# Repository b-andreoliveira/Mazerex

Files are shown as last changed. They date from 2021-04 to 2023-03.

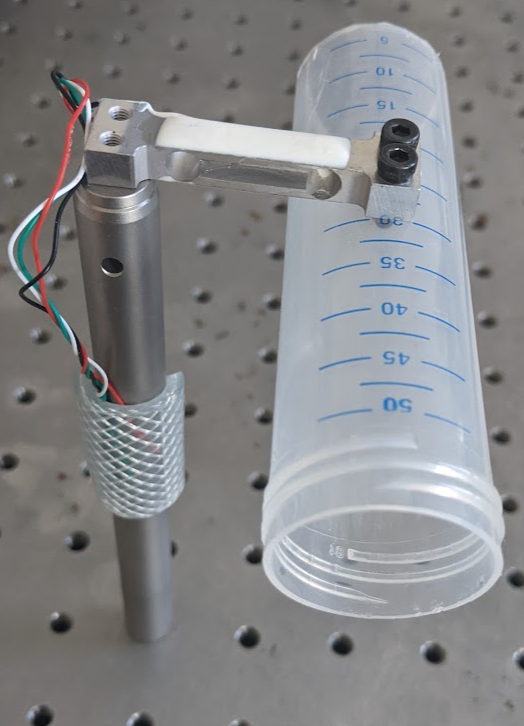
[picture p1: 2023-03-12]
final/weighing_tunnel.png

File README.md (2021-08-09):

# Mazerex

This GitHub page is dedicated to documenting the deleoping process of Mazerex.

For the Internship II report of the MSc Neuroscinces, please go to the 'final' folder, as it contains the final version of the codes and the 3D-printable files.

The python script running in both RaspberryPi I and RaspberryPi II is the same.

 - André Oliveira Borba

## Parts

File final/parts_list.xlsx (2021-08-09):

Item | Quantity | Product no. | Brand/Company | Price per unit (in US$) | Price (in US$) | Link
RaspberryPi 4B | 2 |  | Raspberry foundation | 51.03 | 102.06 | https://www.raspberrystore.nl/PrestaShop/raspberry-pi-v4/227-raspberry-pi-4b2gb-765756931175.html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
Arduino-nano | 1 | #A000005 | Arduino | 23.76 | 23.76 | https://store.arduino.cc/arduino-nano
FED3 | 4 | N/A | Kravitz lab | 178.51 | 714.04 | https://github.com/KravitzLabDevices/FED3
RFID reader ID-20LA (125 kHz) | 4 | #SEN-11828 | Sparkfun | 34.95 | 139.8 | https://www.sparkfun.com/products/11828
RFID breakout board with USB reader | 4 | #SEN-09963 | Sparkfun | 27.95 | 111.8 | https://www.sparkfun.com/products/9963
RFID-tag glass capsule (125 kHz) | 6 | #SEN-09416 | Sparkfun | 4.95 | 29.7 | https://www.sparkfun.com/products/9416
100g load cell | 4 | #SEN-14727 | Sparkfun | 8.95 | 35.8 | https://www.sparkfun.com/products/14727
OpenScale | 4 | #SEN-13261 | Sparkfun | 31.95 | 127.8 | https://www.sparkfun.com/products/13261
green LEDs | 4 | #COM-09592 | Sparkfun | 0.35 | 1.4 | https://www.sparkfun.com/products/9592
red LEDs | 4 | #COM-09590 | Sparkfun | 0.35 | 1.4 | https://www.sparkfun.com/products/9590
piezo transducer (passive buzzer) | 4 | #PS1240P02CT3 | TKD | 0.44 | 1.76 | https://www.kingstate.com.tw/index.php?do=product&id=14
flying-fish infra-red proximity receptor | 4 | #100314 | Yanmis | 9.59 | 38.36 | https://www.amazon.co.uk/dp/B07MJF9Z4K?uh_it=406ac83ca40dd442a51c544e3dd4ecd5_CT
flying saucer running wheel | 4 |  | Ware pet products | 6.29 | 25.16 | https://www.warepet.com/product/03281/flying-saucer-sm.html
generic servomotor | 4 | #ROB-09065 | Sparkfun | 8.95 | 35.8 | https://www.sparkfun.com/products/9065
rotary encoder | 4 | #REC16B50-201 | Copal Electronics | 15.34 | 61.36 | https://nl.rs-online.com/web/p/optical-rotary-encoders/1825634/
relay PCB suitable for Arduino | 1 | #TC-9072496 | Conrad | 9.39 | 9.39 | https://www.amazon.co.uk/dp/B073W6QD9P
stainless steel optical posts 150mm | 4 | #TR150/M | Thor labs | 7.9 | 31.6 | https://www.thorlabs.com/newgrouppage9.cfm?objectgroup_id=1266
stainless steel optical posts 300mm | 4 | #TR300/M | Thor labs | 12.26 | 49.04 | https://www.thorlabs.com/newgrouppage9.cfm?objectgroup_id=1266
25mm optical construction rails 1200mm long | 4 | #XE25L1200/M | Thor labs | 63.37 | 253.48
optical post holders Ø12.7mm, 20mm long | 8 | #PH20/M | Thor labs | 7.74 | 61.92
drop-in T-nuts | 10 | #XE252T2 | Thor labs | 33.28 | 33.28
90º angle post clamps | 8 | #RA90/M | Thor labs | 10.75 | 86
3D-printed doors | 4 | N/A | N/A | N/A | N/A | N/A
3D-printed RFID-antenna supports | 4 | N/A | N/A | N/A | N/A | N/A
3D-printed ladder/slit juncture | 4 | N/A | N/A | N/A | N/A | N/A
TOTAL ESTIMATED PRICE |  |  |  |  | 1974.71
FED3 |  |  |  | Price item | for 1 fed | for 4 feds
Adafruit M0 Adalogger | 4 | #2796 | Adafruit Industries | 20.84 | 20.84
8GB SD card | 4 | #TS8GSDHC10 | Transcend | 13.22 | 13.22
3.6V Lithium-ion rechargeable battery | 4 | #2447-3005 | Ansmann | 39.85 | 39.85
Interrupt button | 4 | #JST PH2 | Adafruit Industries | 2.96 | 2.96
RTC module | 4 | #PCF8523 | Adafruit Industries | 4.97 | 4.97
NeoPixel Stick RGB LED 8 | 4 | #WS2812 | Adafruit Industries | 5.98 | 5.98
Stepper motor PM geared | 4 | #MIKROE-1530 | MikroEletronika | 8 | 8
Sharp memory display breakout | 4 | #3502 | Adafruit Industries | 24.95 | 24.95
1K resistors | 12 | #CFR-25JB-52-1K | Yaego | 0.0258 | 0.0774
Motor shield breakout TB6612 | 4 | #2448 | Adafruit Industries | 4.95 | 4.95
Photointerruptor | 12 | #GP1A57HRJ00F | SHARP/Socle Technology | 3.455 | 10.365
Custom PCB | 4 | N/A | OSHPARK | 42.35 | 42.35
 |  |  |  |  | 0
 |  |  |  |  | 0
 |  |  |  |  | 178.5124

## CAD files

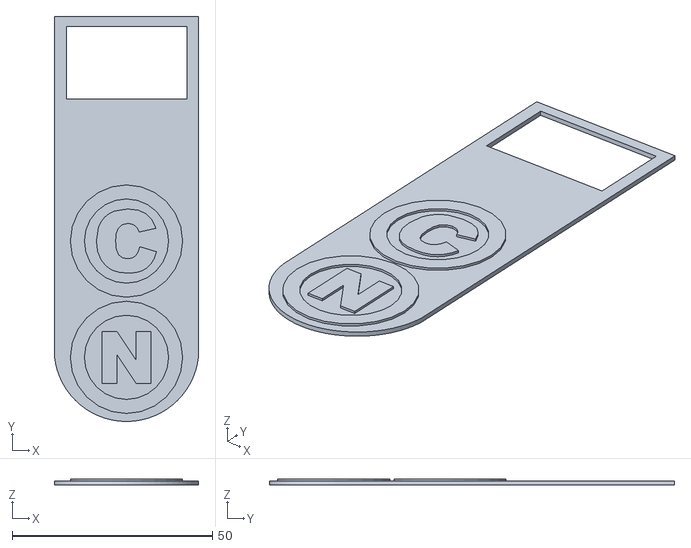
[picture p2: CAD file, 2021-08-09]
final/3D files/mazerex_door.stl
36.0 x 101.0 x 1.50

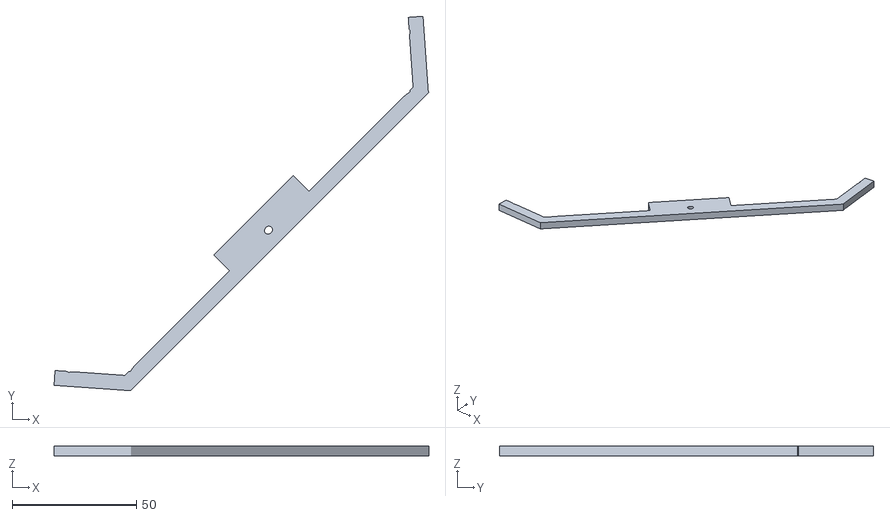
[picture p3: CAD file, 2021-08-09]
final/3D files/servo_arm_new.stl
151.2 x 150.9 x 4.00

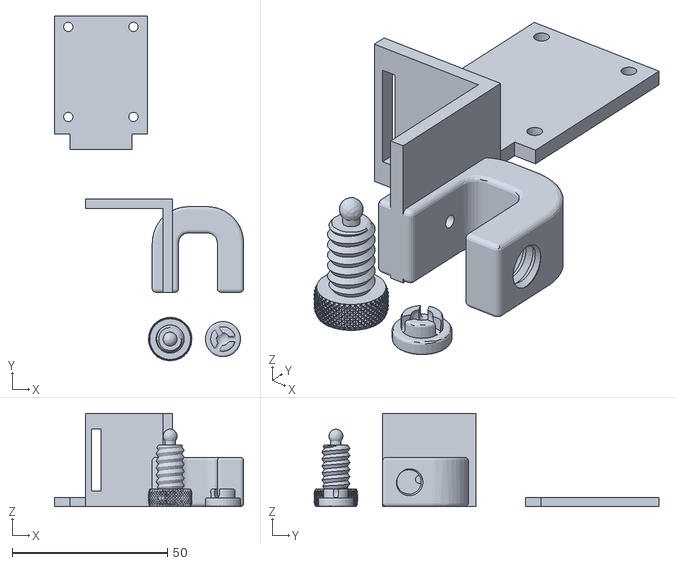
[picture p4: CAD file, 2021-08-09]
final/3D files/RFID_antenna_adaptor.stl
61.0 x 111.1 x 30.0

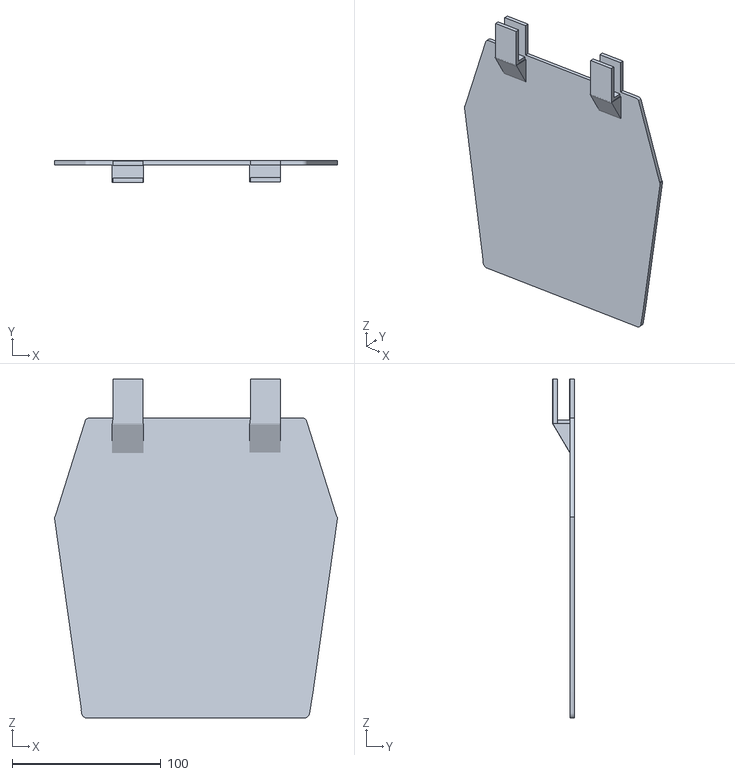
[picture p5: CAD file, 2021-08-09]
final/3D files/mazerex_divisor.stl
190.4 x 14.7 x 227.7

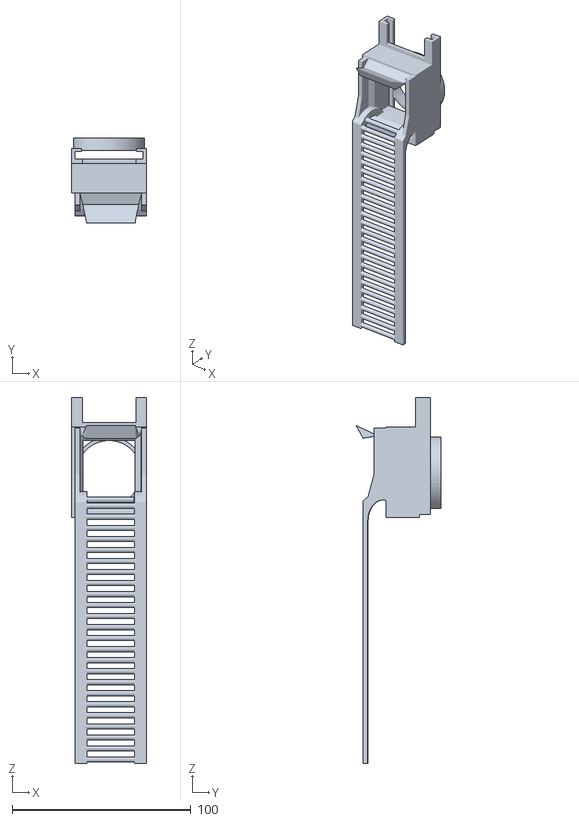
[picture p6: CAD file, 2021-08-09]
final/3D files/ladder-slit_mazerex.stl
42.0 x 47.6 x 204.9

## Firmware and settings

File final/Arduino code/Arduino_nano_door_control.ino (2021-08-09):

#include<Servo.h>
Servo servo1;     // Servo 1
#include<Servo.h>
Servo servo2;     
#include<Servo.h>
Servo servo3;     
#include<Servo.h>
Servo servo4;     

const int servoPin1 = 5;  // output to servos 1-4
const int servoPin2 = 6;
const int servoPin3 = 3;
const int servoPin4 = 9;

const int slowness = 8;   //slowness factor, ms wait between 1deg movements, change to set speed
                           
//SERVO 1
const int d1_food = 75;   //servo positions; calibrate manually//servo positions; calibrate manually
const int d1_social = 125;  
const int d1_close = 100;

//SERVO 2 
const int d2_food = 120;   
const int d2_social = 75;  
const int d2_close = 100; 

//SERVO 3
const int d3_food = 100;   
const int d3_social = 60;  
const int d3_close = 80; 

//SERVO 4
const int d4_food = 45;   
const int d4_social = 95;  
const int d4_close = 70; 

// input commands from Pi 
const int Pd1_food = 2;  
const int Pd1_social = 4;

const int Pd2_food = 7;      
const int Pd2_social = 8;

const int Pd3_food = 10;   
const int Pd3_social = 11;

const int Pd4_food = 12;      
const int Pd4_social = 13;

int pos1_current = d1_food; //initial position variables for servos
int pos1_target = d1_food;
int pos2_current = d2_food; //initial position variables for servos
int pos2_target = d2_food;
int pos3_current = d3_food; //initial position variables for servos
int pos3_target = d3_food;
int pos4_current = d4_food; //initial position variables for servos
int pos4_target = d4_food;

void setup() {
  // put your setup code here, to run once:
  
//check door operation
servo1.attach(servoPin1);
servo1.write(pos1_current); 
pos1_target=d1_close; //will go slowly to closed when arduino code runs correctly without pi input.
delay(500);
servo2.attach(servoPin2);
servo2.write(pos2_current); 
pos2_target=d2_close;
delay(500);
servo3.attach(servoPin3);
servo3.write(pos3_current); 
pos3_target=d3_close;
delay(500);
servo4.attach(servoPin4);
servo4.write(pos4_current); 
pos4_target=d4_close;
delay(500);

pinMode(Pd1_food, INPUT);// input commands from Pi
pinMode(Pd1_social, INPUT);
pinMode(Pd2_food, INPUT);
pinMode(Pd2_social, INPUT);
pinMode(Pd3_food, INPUT);// input commands from Pi
pinMode(Pd3_social, INPUT);
pinMode(Pd4_food, INPUT);
pinMode(Pd4_social, INPUT);

}

void loop() {
  // put your main code here, to run repeatedly:
  
//new servo if loops
  if (pos1_current<pos1_target) //SERVO 1
  {
    pos1_current=pos1_current+1;
    servo1.write(pos1_current);     
    delay(slowness); 
  }
  if (pos1_current>pos1_target)
  {
    pos1_current=pos1_current-1;
    servo1.write(pos1_current);     
    delay(slowness); 
  }
  
  if (pos2_current<pos2_target) //SERVO 2
  {
    pos2_current=pos2_current+1;
    servo2.write(pos2_current);     
    delay(slowness); 
  }
  if (pos2_current>pos2_target)
  {
    pos2_current=pos2_current-1;
    servo2.write(pos2_current);     
    delay(slowness); 
  }

  if (pos3_current<pos3_target) //SERVO 3
  {
    pos3_current=pos3_current+1;
    servo3.write(pos3_current);     
    delay(slowness); 
  }
  if (pos3_current>pos3_target)
  {
    pos3_current=pos3_current-1;
    servo3.write(pos3_current);     
    delay(slowness); 
  }
  
  if (pos4_current<pos4_target) //SERVO 4
  {
    pos4_current=pos4_current+1;
    servo4.write(pos4_current);     
    delay(slowness); 
  }
  if (pos4_current>pos4_target)
  {
    pos4_current=pos4_current-1;
    servo4.write(pos4_current);     
    delay(slowness); 
  }
  
  //target commands
  
  //SERVO 1
    
  if ((digitalRead(Pd1_social) == HIGH)) 
    {
    pos1_target=d1_social;
    }
  if ((digitalRead(Pd1_food) == HIGH)) 
    {
    pos1_target=d1_food;
    }
  if ((digitalRead(Pd1_food) == LOW) && (digitalRead(Pd1_social) == LOW)) 
    {
    pos1_target=d1_close;
    }
  
  //SERVO 2
  if ((digitalRead(Pd2_social) == HIGH)) 
    {
    pos2_target=d2_social;
    }
  if ((digitalRead(Pd2_food) == HIGH)) 
    {
    pos2_target=d2_food;
    }
  if ((digitalRead(Pd2_food) == LOW) && (digitalRead(Pd2_social) == LOW)) 
    {
    pos2_target=d2_close;
    }
  
  //SERVO 3
  if ((digitalRead(Pd3_social) == HIGH)) 
    {
    pos3_target=d3_social;
    }
  if ((digitalRead(Pd3_food) == HIGH)) 
    {
    pos3_target=d3_food;
    }
  if ((digitalRead(Pd3_food) == LOW) && (digitalRead(Pd3_social) == LOW)) 
    {
    pos3_target=d3_close;
    }
  
  //SERVO 4
  if ((digitalRead(Pd4_social) == HIGH)) 
    {
    pos4_target=d4_social;
    }
  if ((digitalRead(Pd4_food) == HIGH)) 
    {
    pos4_target=d4_food;
    }
  if ((digitalRead(Pd4_food) == LOW) && (digitalRead(Pd4_social) == LOW)) 
    {
    pos4_target=d4_close;
    }

}

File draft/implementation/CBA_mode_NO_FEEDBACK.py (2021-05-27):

#import libraries
import os
import time
import serial
import threading
import pandas as pd
from IOPi import IOPi
import RPi.GPIO as GPIO
import statistics as stats
from datetime import datetime

# change directory to document data folder
os.chdir("/home/pi/Documents/data/dummy_data")

'''
-------------------------------------------------------------------------------------------------------------------
-------------------------------------------------------------------------------------------------------------------
INITIALIZE PARAMETERS AND VARIABES
-------------------------------------------------------------------------------------------------------------------
-------------------------------------------------------------------------------------------------------------------
'''

'''set GPIO numbering mode'''
GPIO.setmode(GPIO.BOARD)
GPIO.cleanup()

''' set serial ports for getting OpenScale data '''
#initialize serial port for OpenScale mouse A
ser_A = serial.Serial()
ser_A.port = '/dev/ttyUSB1' #OpenScale serial port ALWAYS CHECK WHETHER THE PORT IS CORRECT!!!!!!!
ser_A.baudrate = 9600
ser_A.timeout = 100000 # we do not want the device to timeout
# test device connection
ser_A.close()
ser_A.open()
ser_A.flush()
if ser_A.is_open==True:
    print("\nScale A ok. Configuration:\n")
    print(ser_A, "\n") #print serial parameters
ser_A.close()

#initialize serial port for OpenScale mouse B
ser_B = serial.Serial()
ser_B.port = '/dev/ttyUSB2' #OpenScale serial port ALWAYS CHECK WHETHER THE PORT IS CORRECT!!!!!!!
ser_B.baudrate = 9600
ser_B.timeout = 100000 # we do not want the device to timeout
# test device connection
ser_B.close()
ser_B.open()
ser_B.flush()
if ser_B.is_open==True:
    print("\nScale B ok. Configuration:\n")
    print(ser_B, "\n") #print serial parameters
ser_B.close()

''' set serial ports for getting RFID antenna signal '''
#initialize serial port for RFID reader mouse A
RFID_A = serial.Serial()
RFID_A.port = '/dev/ttyS0' #RFID antenna serial port ALWAYS CHECK WHETHER THE PORT IS CORRECT!!!!!!!
RFID_A.baudrate = 9600
RFID_A.timeout = 100000 # we do not want the device to timeout
# test device connection
RFID_A.close()
RFID_A.open()
RFID_A.flush()
if RFID_A.is_open==True:
    print("\nRFID reader A ok. Configuration:\n")
    print(RFID_A, "\n") #print serial parameters
RFID_A.close()

#initialize serial port for RFID reader mouse B
RFID_B = serial.Serial()
RFID_B.port = '/dev/ttyAMA1' #RFID antenna serial port ALWAYS CHECK WHETHER THE PORT IS CORRECT!!!!!!!
RFID_B.baudrate = 9600
RFID_B.timeout = 100000 # we do not want the device to timeout
# test device connection
RFID_B.close()
RFID_B.open()
RFID_B.flush()
if RFID_B.is_open==True:
    print("\nRFID reader B ok. Configuration:\n")
    print(RFID_B, "\n") #print serial parameters
RFID_B.close()

''' set door pins '''
#mouse A
PdA_food = 3
PdA_social = 5
GPIO.setup(PdA_food,GPIO.OUT)
GPIO.setup(PdA_social, GPIO.OUT)
GPIO.output(PdA_food,False)
GPIO.output(PdA_social, True) #SOCIAL position

#mouse B
PdB_food = 7
PdB_social = 11
GPIO.setup(PdB_food,GPIO.OUT)
GPIO.setup(PdB_social, GPIO.OUT)
GPIO.output(PdB_food,False)
GPIO.output(PdB_social, True) #SOCIAL position

''' set pins for buzzers and LEDs '''
#buzzer tones
heavier_buzz_1 = 700
heavier_buzz_2 = 589
not_heavier_buzz_1 = 131
not_heavier_buzz_2 = 165

#mouse A
#set pin output to buzzer and LEDs
gLED_A = 22
rLED_A = 24
buzzer_A = 26
GPIO.setup(gLED_A, GPIO.OUT)
GPIO.setup(rLED_A, GPIO.OUT)
GPIO.setup(buzzer_A, GPIO.OUT)
buzz_A = GPIO.PWM(buzzer_A, 1) #starting frequency is 1 (inaudible)
GPIO.setup(gLED_A, GPIO.OUT)
GPIO.setup(rLED_A, GPIO.OUT)
GPIO.output(gLED_A, False)
GPIO.output(rLED_A,False)

#mouse B
gLED_B = 36
rLED_B = 32
buzzer_B = 40
GPIO.setup(gLED_B, GPIO.OUT)
GPIO.setup(rLED_B, GPIO.OUT)
GPIO.setup(buzzer_B, GPIO.OUT)
buzz_B = GPIO.PWM(buzzer_B, 1) #starting frequency is 1 (inaudible)
GPIO.setup(gLED_B, GPIO.OUT)
GPIO.setup(rLED_B, GPIO.OUT)
GPIO.output(gLED_B, False)
GPIO.output(rLED_B,False)

''' set pins for running wheel '''
#mouse A
#set pin inputs from running wheel rotary encoder and initialize variables
dt_A = 12
GPIO.setup(dt_A, GPIO.IN)
dtLastState_A = GPIO.input(dt_A)
wheel_counter_A = 0;
cycle_A = 160; #calibration value (1200 for old wheels, 160 for new ones)
limit_A = cycle_A;
turn_A = 0;

#mouse B
#set pin inputs from running wheel rotary encoder and initialize variables
dt_B = 15
GPIO.setup(dt_B, GPIO.IN)
dtLastState_B = GPIO.input(dt_B)
wheel_counter_B = 0;
cycle_B = 160; #calibration value (1200 for old wheels, 160 for new ones)
limit_B = cycle_B;
turn_B = 0;

''' set pins for IR proximity detectors '''
#mouse A
#set pins for beam break (flying fish) proximity scanner
IR_A = 8
GPIO.setup(IR_A, GPIO.IN)

#mouse B
#set pins for beam break (flying fish) proximity scanner
IR_B = 13
GPIO.setup(IR_B, GPIO.IN)

''' sets pins for sending commands to the FED (Pi --> FED) '''
#mouse A
#set pins for output to FED_A
writeFED_A = 18
GPIO.setup(writeFED_A, GPIO.OUT)
GPIO.output(writeFED_A, False)

#mouse B
#set pins for output to FED_B
writeFED_B = 21
GPIO.setup(writeFED_B, GPIO.OUT)
GPIO.output(writeFED_B, False)

''' set pins for reading input from FED (FED --> Pi) '''
#mouse A
#set pin for input from FED_A
read_FED_A = 16
GPIO.setup(read_FED_A, GPIO.IN, pull_up_down=GPIO.PUD_DOWN)
GPIO.add_event_detect(read_FED_A, GPIO.RISING) #detects rising voltage
pellet_counter_A = 0

#mouse B
#set pin for input from FED_B
read_FED_B = 19
GPIO.setup(read_FED_B, GPIO.IN, pull_up_down=GPIO.PUD_DOWN)
GPIO.add_event_detect(read_FED_B, GPIO.RISING) #detects rising voltage
pellet_counter_B = 0

''' set pins for air puffs '''
#mouse A
airpuff_A = 33
GPIO.setup(airpuff_A, GPIO.OUT)
GPIO.output(airpuff_A, False)

#mouse B
airpuff_B = 35
GPIO.setup(airpuff_B, GPIO.OUT)
GPIO.setup(airpuff_B, False)

'''initialize MODE variable'''
MODE_A = 0
MODE_B = 0

lines_to_chuck = 15

print("please define pellet price: \n 0 = 1 turn \n 1 = 5 turns \n 2 = 10 turns \n 3 = 25 turns \n 4 = 50 turns \n 5 = 100 turns")

exercise_key = input()

'''
-------------------------------------------------------------------------------------------------------------------
-------------------------------------------------------------------------------------------------------------------
DEFINE FUNCTIONS TO BE USED IN THE CODE EXECUTION
-------------------------------------------------------------------------------------------------------------------
-------------------------------------------------------------------------------------------------------------------
'''

'''
GENERAL FUNCTIONS ########################################################################################
'''

def countdown():#define countdown function (for testing only)
    for x in range(5,-1, -1):
        print("countdown: " + str(x))
        time.sleep(1)
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

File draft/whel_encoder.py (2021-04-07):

import serial
import time
import RPi.GPIO as GPIO
import os
import pandas as pd
import statistics as stats
import time
from datetime import datetime

GPIO.setmode(GPIO.BOARD)
#set pin inputs from running wheel rotary encoder
clk = 37
dt = 38

GPIO.setup(clk,GPIO.IN)
GPIO.setup(dt,GPIO.IN)
clkLastState = GPIO.input(clk)
dtLastState = GPIO.input(dt)

counter = 0;
cycle = 1200; #calibration value
limit = cycle;
turn = 0;

try:  
    while True:
            clkState = GPIO.input(clk)
            dtState = GPIO.input(dt)
            
#             if clkState != clkLastState:
#                 counter += 1
#                 
# #                 print(counter)
#                 clkLastState = clkState
            
            if dtState != dtLastState:
                counter += 1
#                 print(counter)
                dtLastState = dtState
                
            if counter >= limit:
                print(counter)
                turn = counter/cycle
                print(turn)
                limit=counter+cycle              
finally:
    GPIO.cleanup()

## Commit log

2021-03-24 Create arduino_pi_servo.ino
    code flushed to the arduino nano, will control servos based on input from Pi.
    final positions and pin numbers still need to be adjusted for multiplexing for 4 servos.
2021-06-06 Add files via upload
    Andre - can you restructure the code like shown here please. Don't change pin designations. All protocols should be on one code and it should be commented better.
